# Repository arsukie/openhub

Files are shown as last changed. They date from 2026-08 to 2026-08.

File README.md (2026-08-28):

# OpenHub

An open-source USB 2.0 hub. USB-C in, 4 ports out (2x USB-C, 2x USB-A)

> schematic's done, PCB is routed, board's off to fab. what could go wrong

## What it is

- USB 2.0 High-Speed (480 Mbps), running on a CoreChips **SL2.1A** hub controller (SOP-16)
- USB-C upstream (USBC1) - configured as a **sink** via 5.1kΩ CC pull-downs (Rd), so it correctly IDs as a device drawing power
- 2x USB-C downstream (USBC2, USBC3) - configured as **sources** via 56kΩ CC pull-ups (Rp), advertising default USB power out
- 2x USB-A downstream, wired straight off the controller's remaining data channels
- **SY6280AAC** current-limited power switch (U1) on the power path, current limit set via a 4.7kΩ ISET resistor (R8) - so a bad downstream device doesn't take the whole hub down with it
- EN pin on the power switch tied directly to VBUS, so downstream power just turns on the moment the hub gets plugged in, no extra logic needed
- Status LED with a 1kΩ series resistor because a silent hub is a suspicious hub
- 12MHz crystal + 15pF load caps for the controller clock
- 10µF / 100nF decoupling pairs at every rail (VDD18/VDD33/VDD5) and at each port, because unstable rails are how you get a board that works on your desk and nowhere else

## Status
Schematic + routing: done.

# Bill of Materials
 
## Selected Parts (12 items)
 
| Part Detail | Selected by | Top Designator | Qty | Source | Ext. Price |
|---|---|---|---|---|---|
| CL21A106KAYNNNE (Basic, C15850) | System | C10,C11,C12,C13... | 10 | JLCPCB | $0.9600 |
| TYPE-C-31-M-12 (Extended, C165948) | System | USBC1,USBC2,USB... | 6 | JLCPCB | $1.1136 |
| SL2.1A (Extended, C6798314) | Customer | U2 | 2 | JLCPCB | $0.5086 |
| 0603WAF5101T5E (Basic, C23186) | System | R1,R2 | 4 | JLCPCB | $0.0100 |
| CL10A106MA8NRNC (Basic, C96446) | System | C1,C2 | 4 | JLCPCB | $0.3168 |
| SY6280AAC (Extended, C55136) | System | U1 | 5 | JLCPCB | $0.4795 |
| HoLTT0603-1/10W-4.7K-1% (Extended, C2904521) | System | R8 | 6 | JLCPCB | $0.2310 |
| USB-231-ARY (Extended, C720525) | System | USB1,USB2 | 4 | JLCPCB | $0.7768 |
| A-SP192DGHC-C01-4T (Extended, C19171301) | System | LED1 | 20 | JLCPCB | $0.5600 |
| CC0603KRX7R9BB104 (Basic, C14663) | System | C5,C6,C7,C8,C9,... | 14 | JLCPCB | $0.2100 |
| RC0805FR-071KL (Extended, C95781) | System | R7 | 20 | JLCPCB | $0.1140 |
| CL10C150JB8NNNC (Basic, C1644) | System | C3,C4 | 4 | JLCPCB | $0.0556 |
 
## PCB & Shipping
 
| Type | Item | Description | Qty | Build Time | Price |
|---|---|---|---|---|---|
| PCB | Gerber_PCB1_2026-08-09_Y6 | PCB prototype: Y6-13163216A, Black, 1.6 Thickness, HASL(with lead) | 5 pcs | 24 hours | $4.00 |
| PCBA | Gerber_PCB1_2026-08-09_Y6 | Economic PCBA: SMT026080960460-13163216A, Assemble top side | 2 pcs | 2 - 3 days | $39.07 |
| PCB | Gerber_PCB1_2026-08-16_Y8 | PCB prototype: Y8-13163216A, Green, 1.6 Thickness, HASL(with lead) | 5 pcs | 3 - 4 days | $7.00 |
 
| | |
|---|---|
| **PCB (Merchandise)** | $50.07 |
| Shipping | $18.21 |
| **Subtotal** | **$68.28** |

## Cart





## Schematics & 3D view
Schematic
3D_View

## Milestones

1. Design finalization - schematic + routing done

Built by **Arjun Khanal** @aruskie

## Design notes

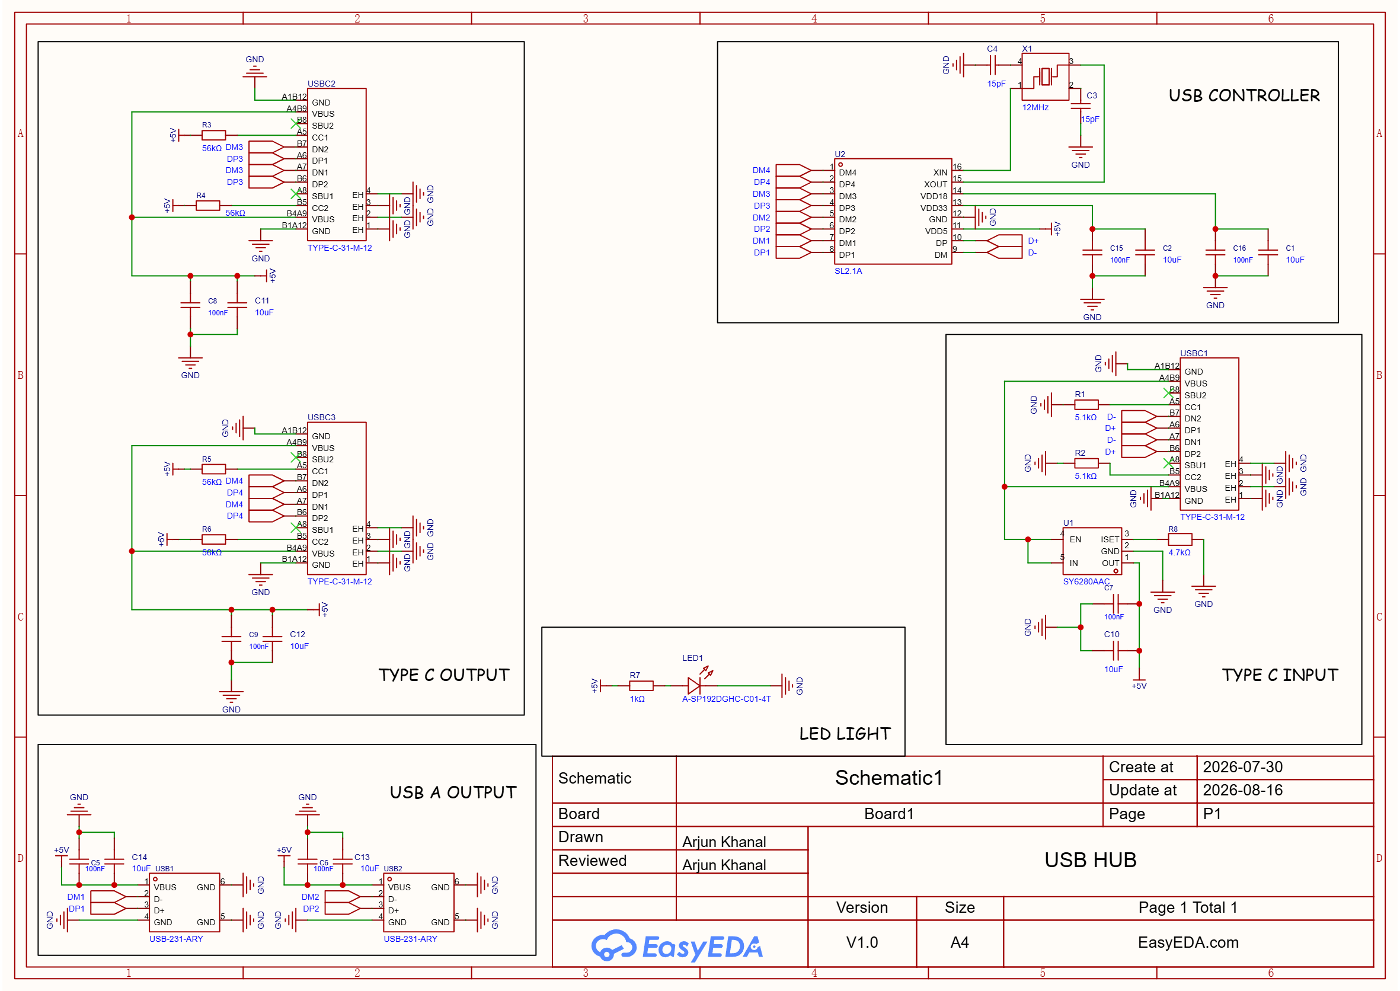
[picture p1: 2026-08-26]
Schematic.png

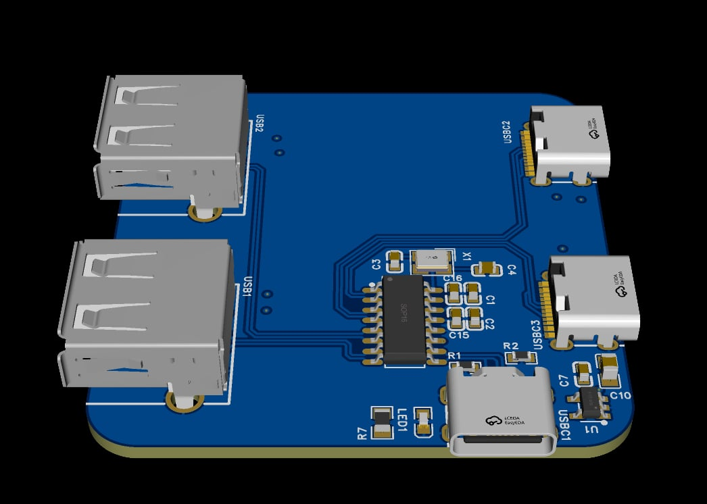
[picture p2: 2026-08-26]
3D_View.png

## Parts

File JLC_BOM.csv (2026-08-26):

No. | Quantity | Comment | Designator | Footprint | Value | Manufacturer Part | Manufacturer | Supplier Part | Supplier
1 | 2 | 10uF | C1,C2 | C0603 | 10uF | CL10A106MA8NRNC | SAMSUNG(三星) | C96446 | LCSC
2 | 2 | 15pF | C3,C4 | C0603 | 15pF | CL10C150JB8NNNC | SAMSUNG(三星) | C1644 | LCSC
3 | 7 | 100nF | C5,C6,C7,C8,C9,C15,C16 | C0603 | 100nF | CC0603KRX7R9BB104 | YAGEO(国巨) | C14663 | LCSC
4 | 5 | 10uF | C10,C11,C12,C13,C14 | C0805 | 10uF | CL21A106KAYNNNE | SAMSUNG(三星) | C15850 | LCSC
5 | 1 | A-SP192DGHC-C01-4T | LED1 | LED0603-FD |  | A-SP192DGHC-C01-4T | Amicc(欧密格光电) | C19171301 | LCSC
6 | 2 | 5.1kΩ | R1,R2 | R0603 | 5.1kΩ | 0603WAF5101T5E | UNI-ROYAL(厚声) | C23186 | LCSC
7 | 4 | 56kΩ | R3,R4,R5,R6 | R0603 | 56kΩ | 0603WAF5602T5E | UNI-ROYAL(厚声) | C23206 | LCSC
8 | 1 | 1kΩ | R7 | R0805 | 1kΩ | RC0805FR-071KL | YAGEO(国巨) | C95781 | LCSC
9 | 1 | 4.7kΩ | R8 | R0603 | 4.7kΩ | HoLTT0603-1/10W-4.7K-1% | Milliohm(毫欧) | C2904521 | LCSC
10 | 1 | SY6280AAC | U1 | SOT-23-5_L3.0-W1.7-P0.95-LS2.8-BL |  | SY6280AAC | Silergy(矽力杰) | C55136 | LCSC
11 | 1 | SL2.1A | U2 | SOP-16_L10.0-W3.9-P1.27-LS6.0-BL |  | SL2.1A | CoreChips(和芯润德) | C192893 | LCSC
12 | 2 | USB-231-ARY | USB1,USB2 | USB-A-TH_USB-231-ARY |  | USB-231-ARY | XUNPU(讯普) | C720525 | LCSC
13 | 3 | TYPE-C-31-M-12 | USBC1,USBC2,USBC3 | USB-C_SMD-TYPE-C-31-M-12_1 |  | TYPE-C-31-M-12 | 韩国韩荣 | C165948 | LCSC
14 | 1 | 12MHz | X1 | CRYSTAL-SMD_4P-L3.2-W2.5-BL | 12MHz | X322512MSB4SI | YXC(扬兴晶振) | C9002 | LCSC

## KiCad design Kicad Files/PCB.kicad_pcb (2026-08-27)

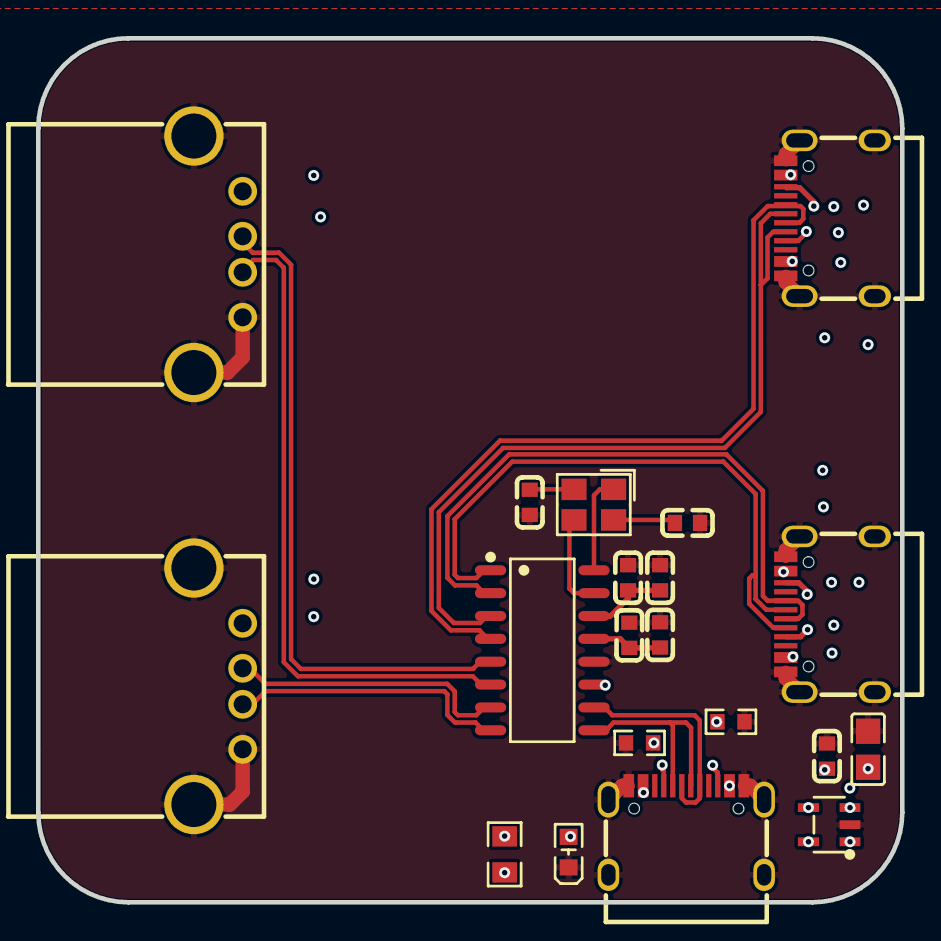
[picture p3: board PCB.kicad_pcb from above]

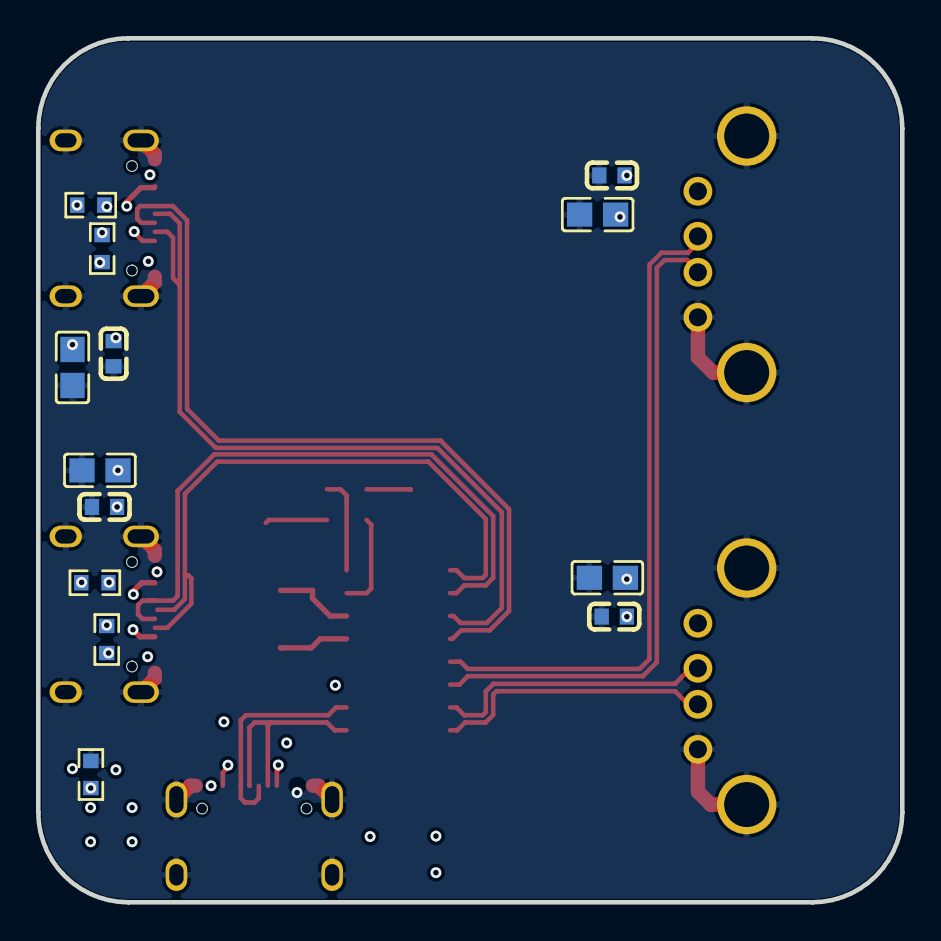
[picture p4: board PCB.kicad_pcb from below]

Board: 4 copper layers, 48.0 x 48.0 mm, 33 parts (13 on the bottom side), 27 nets.

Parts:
C1, C2, C3, C4, C5, C6, C7, C8, C9, C15, C16: C0603
C10, C11, C12, C13, C14: C0805
LED1: LED0603-FD
R1, R2, R3, R4, R5, R6, R8: R0603
R7: R0805
U1: SOT-23-5_L3.0-W1.7-P0.95-LS2.8-BL
U2: SOP-16_L10.0-W3.9-P1.27-LS6.0-BL
USB1, USB2: USB-A-TH_USB-231-ARY
USBC1, USBC2, USBC3: USB-C_SMD-TYPE-C-31-M-12_1
X1: CRYSTAL-SMD_4P-L3.2-W2.5-BL

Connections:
$1N151: C1.1, C16.2, U2.14
$1N152: C2.1, C15.2, U2.13
$1N156: U2.15, X1.3
$1N157: U2.16, X1.1
$1N158: C4.1, X1.4
$1N159: C3.2, X1.2
$1N181: R1.2, USBC1.A5
$1N182: R2.1, USBC1.B5
$1N206: R4.2, USBC2.B5
$1N207: R3.2, USBC2.A5
$1N223: R6.2, USBC3.B5
$1N224: R5.2, USBC3.A5
$1N239: LED1.1, R7.2
$1N246: U1.4, U1.5, USBC1.A4B9, USBC1.B4A9
$1N248: R8.1, U1.3
+5V: C5.1, C6.1, C7.2, C8.2, C9.2, C10.2, C11.2, C12.2, C13.1, C14.1, R3.1, R4.1, R5.1, R6.1, R7.1, U1.1, U2.11, USB1.1, USB2.1, USBC2.A4B9, USBC2.B4A9, USBC3.A4B9, USBC3.B4A9
D+: U2.10, USBC1.A6, USBC1.B6
D-: U2.9, USBC1.A7, USBC1.B7
DM1: U2.7, USB1.2
DM2: U2.5, USB2.2
DM3: U2.3, USBC2.A7, USBC2.B7
DM4: U2.1, USBC3.A7, USBC3.B7
DP1: U2.8, USB1.3
DP2: U2.6, USB2.3
DP3: U2.4, USBC2.A6, USBC2.B6
DP4: U2.2, USBC3.A6, USBC3.B6
GND: C1.2, C2.2, C3.1, C4.2, C5.2, C6.2, C7.1, C8.1, C9.1, C10.1, C11.1, C12.1, C13.2, C14.2, C15.1, C16.1, LED1.2, R1.1, R2.2, R8.2, U1.2, U2.12, USB1.4, USB1.5, USB1.6, USB2.4, USB2.5, USB2.6, USBC1.1, USBC1.2, USBC1.3, USBC1.4, USBC1.A1B12, USBC1.B1A12, USBC2.1, USBC2.2, USBC2.3, USBC2.4, USBC2.A1B12, USBC2.B1A12, USBC3.1, USBC3.2, USBC3.3, USBC3.4, USBC3.A1B12, USBC3.B1A12

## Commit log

2026-07-30 Project Init and schematic half way
2026-07-31 Schematic Completed
2026-07-31 I forgot to push BTW schematic was done and PCB design also done IG
2026-08-02 Workin on Kicad for the Routing
2026-08-04 Schematic Update v2
2026-08-06 Update of the holes
2026-08-15 Updated the Schematic layout
2026-08-17 4 layer PCB update
2026-08-19 Minor LED fix
2026-08-26 Files Update
    [BOM.csv, Pick_Place.csv]
2026-08-26 Readme Update Schematic
2026-08-27 Kicad Files Update
    [PCB.kicad_pcb, Schematic.kicad_sch]
2026-08-28 BOM update
    [BOM.csv]
2026-08-28 JLC BOM update for direct orderin
    [JLC_BOM.csv]
